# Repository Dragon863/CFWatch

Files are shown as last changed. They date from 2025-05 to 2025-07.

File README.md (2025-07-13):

# ⌚ CFWatch
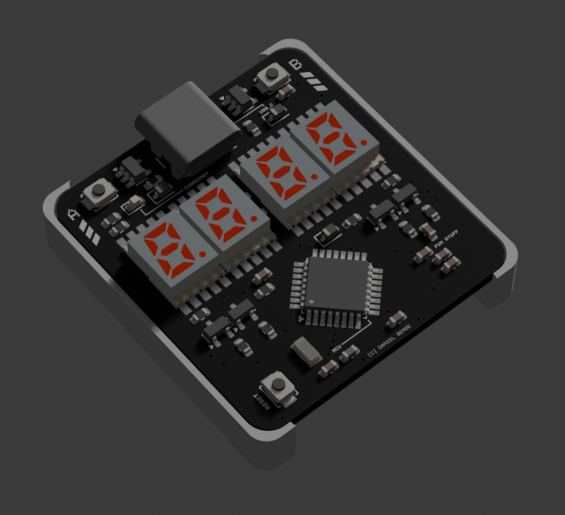
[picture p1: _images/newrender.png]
render


## What is this?

CFWatch is a project that I've been wanting to build for years now. I've always dreamed of building a watch, but was never quite sure where to start - sure, the pinetime and other hackable watches were really cool, but they never quite felt "personal" or quite reflective of the stuff I enjoy. Eventually I decided I'd just build my own, but I didn't really have the knowledge or skills to do so until very recently, so when [highway](https://highway.hackclub.com/) came along I decided it was finally time! The "CF" in "CFWatch" came from [r/cassettefuturism](https://old.reddit.com/r/cassettefuturism/top/?sort=top&t=all), a huge source of design inspiration for this

## Hardware Overview

The current revision has:
- USB-C charging & programming (requires bootloader)
- 4x red 7-segment displays
- 2x individually programmable buttons
- LIR2032 battery with theoretical battery life of several months (untested)
- SAMD21 microcontroller for low power usage

The board layout is optimised for being assembled with JLCPCB's PCBA service, with every component apart from the battery on the front of the PCB. I would recommend hand soldering the cell mount to save costs.

## Repository Layout

The repo is structured as follows:
- PCB-related KiCad files in the `PCB/`
- FreeCAD case design in `CAD/`
- Files for creating the cover render in `Blender/`
- For a rough BOM, see `BOM.csv`
- For my development log, see `JOURNAL.md

> [!CAUTION]
> Version 1 has SEVERAL known issues! If you plan to use this to have your own manufactured, please use the V2 design made in EasyEDA and double check everything in the schematic and PCB; I am not responsible for any non-functional boards!

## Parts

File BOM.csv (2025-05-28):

Item | Estimated price
PCB Assembly (JLCPCB) | $110
J-Link clone (Aliexpress) | $10
2x Keystone 1060 coin cell holders (LCSC) | $9
2x LIR2032 coin cells (Aliexpress) | $5

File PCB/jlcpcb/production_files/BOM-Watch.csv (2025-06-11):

Comment | Designator | Footprint | LCSC | Quantity
2.2uH | L1 | L_0805_2012Metric | C1043 | 1
MCP73831-2-OT | U1 | SOT-23-5 | C14879 | 1
36.5k | R21 | R_0402_1005Metric | C15011 | 1
TPS63900 | U2 | WSON-10-1EP_2.5x2.5mm_P0.5mm_EP1.2x2mm_ThermalVias | C1518762 | 1
D | D1,D2 | D_SOD-323 | C191023 | 2
4.7u | C8 | C_0603_1608Metric | C19666 | 1
KCSA02-105 | Dig1,Dig2,Dig3,Dig4 | KCSC02-105 | C22462656 | 4
SW_Push | SW1,SW3,SW4 | SW_SPST_B3U-1000P | C231329 | 3
150 | R13,R14,R15,R16,R6,R7,R8,R9 | R_0402_1005Metric | C25082 | 8
220 | R4 | R_0402_1005Metric | C25091 | 1
390 | R17,R18,R19,R20 | R_0402_1005Metric | C25109 | 4
10k | R5 | R_0402_1005Metric | C25744 | 1
27k | R1 | R_0402_1005Metric | C25771 | 1
5.1k | R2,R3 | R_0402_1005Metric | C25905 | 2
USB_C_Receptacle_USB2.0_14P | J1 | USB_C_Receptacle_HCTL_HC-TYPE-C-16P-01A | C2988369 | 1
32768Hz | Y2 | Crystal_SMD_3215-2Pin_3.2x1.5mm | C32346 | 1
10pF | C10,C9 | C_0402_1005Metric | C32949 | 2
LED | D3 | LED_0402_1005Metric | C33115 | 1
1uF | C1,C5,C6,C7 | C_0402_1005Metric | C52923 | 4
2N3906 | Q1,Q2,Q3,Q4 | SOT-23 | C5300004 | 4
22uF | C_OUT1 | C_0603_1608Metric | C59461 | 1
ATSAMD21E18A-A | U7 | TQFP-32_7x7mm_P0.8mm | C618770 | 1
10uF | C_IN1 | C_0603_1608Metric | C96446 | 1

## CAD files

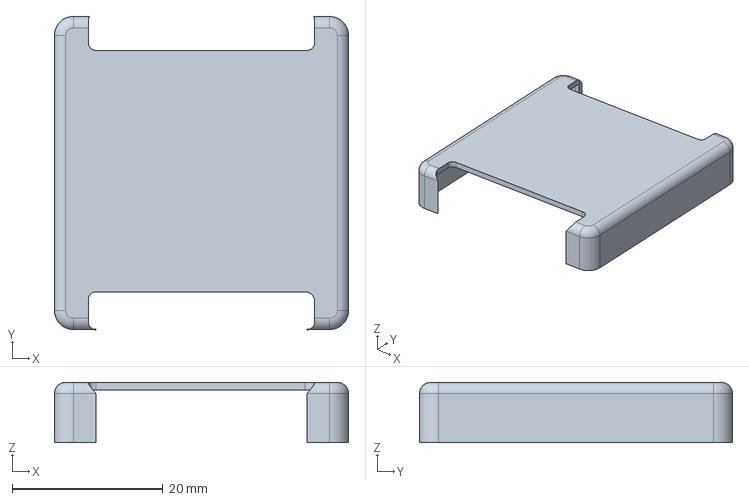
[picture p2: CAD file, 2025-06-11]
CAD/watch.FCStd
39.0 x 41.5 x 8.00 mm

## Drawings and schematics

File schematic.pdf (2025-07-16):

GND B1A12 VBUS B4A9 CC2 B5 SBU1 A8 DP2 B6 DN1 A7 DP1 A6 DN2 B7 CC1 A5 SBU2 B8 VBUS A4B9 GND A1B12

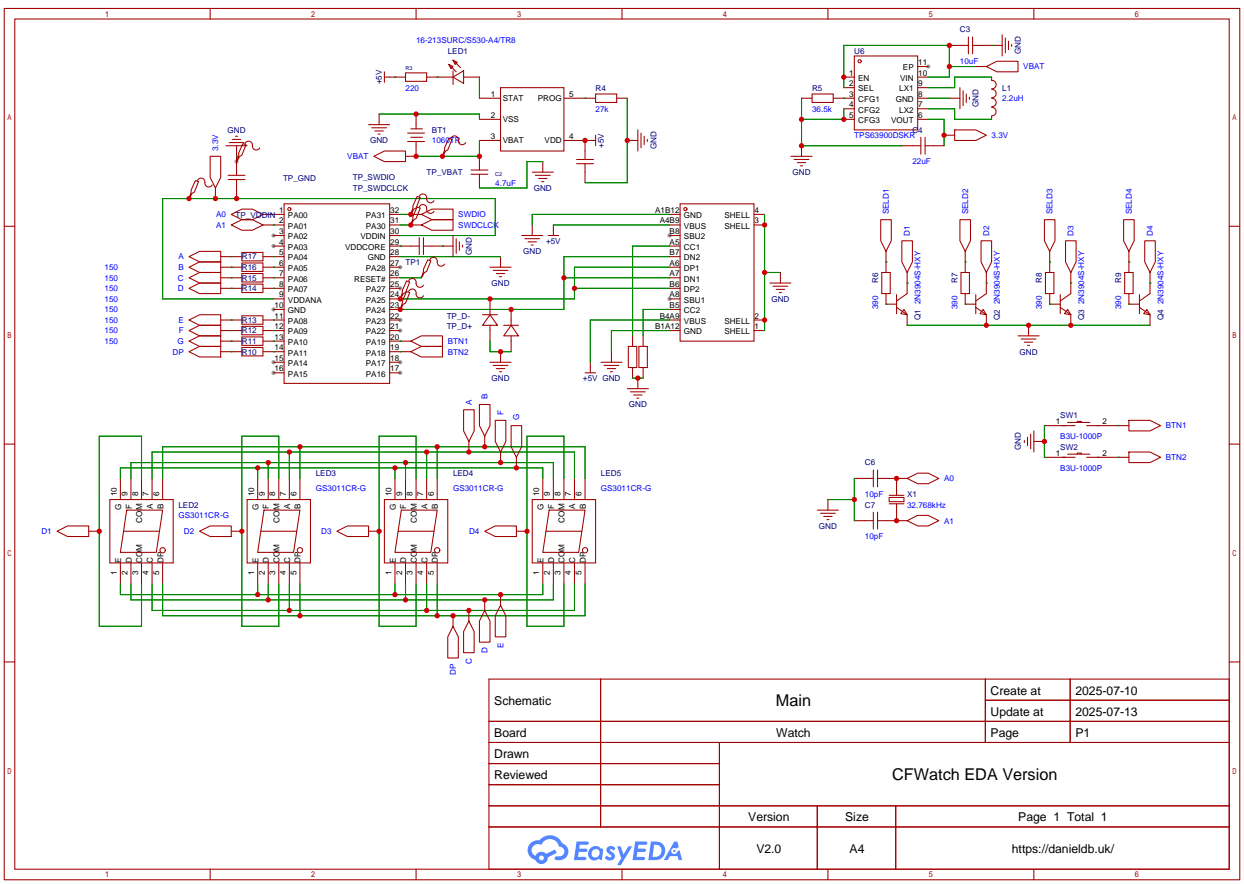
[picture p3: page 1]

Schematic | Main | Create at | 2025-07-10

Update at | 2025-07-13

Board | Watch | Page | P1
Drawn | | CFWatch EDA Version
Reviewed

Version | Size | Page 1 Total 1

V2.0 | A4 | https://danieldb.uk/

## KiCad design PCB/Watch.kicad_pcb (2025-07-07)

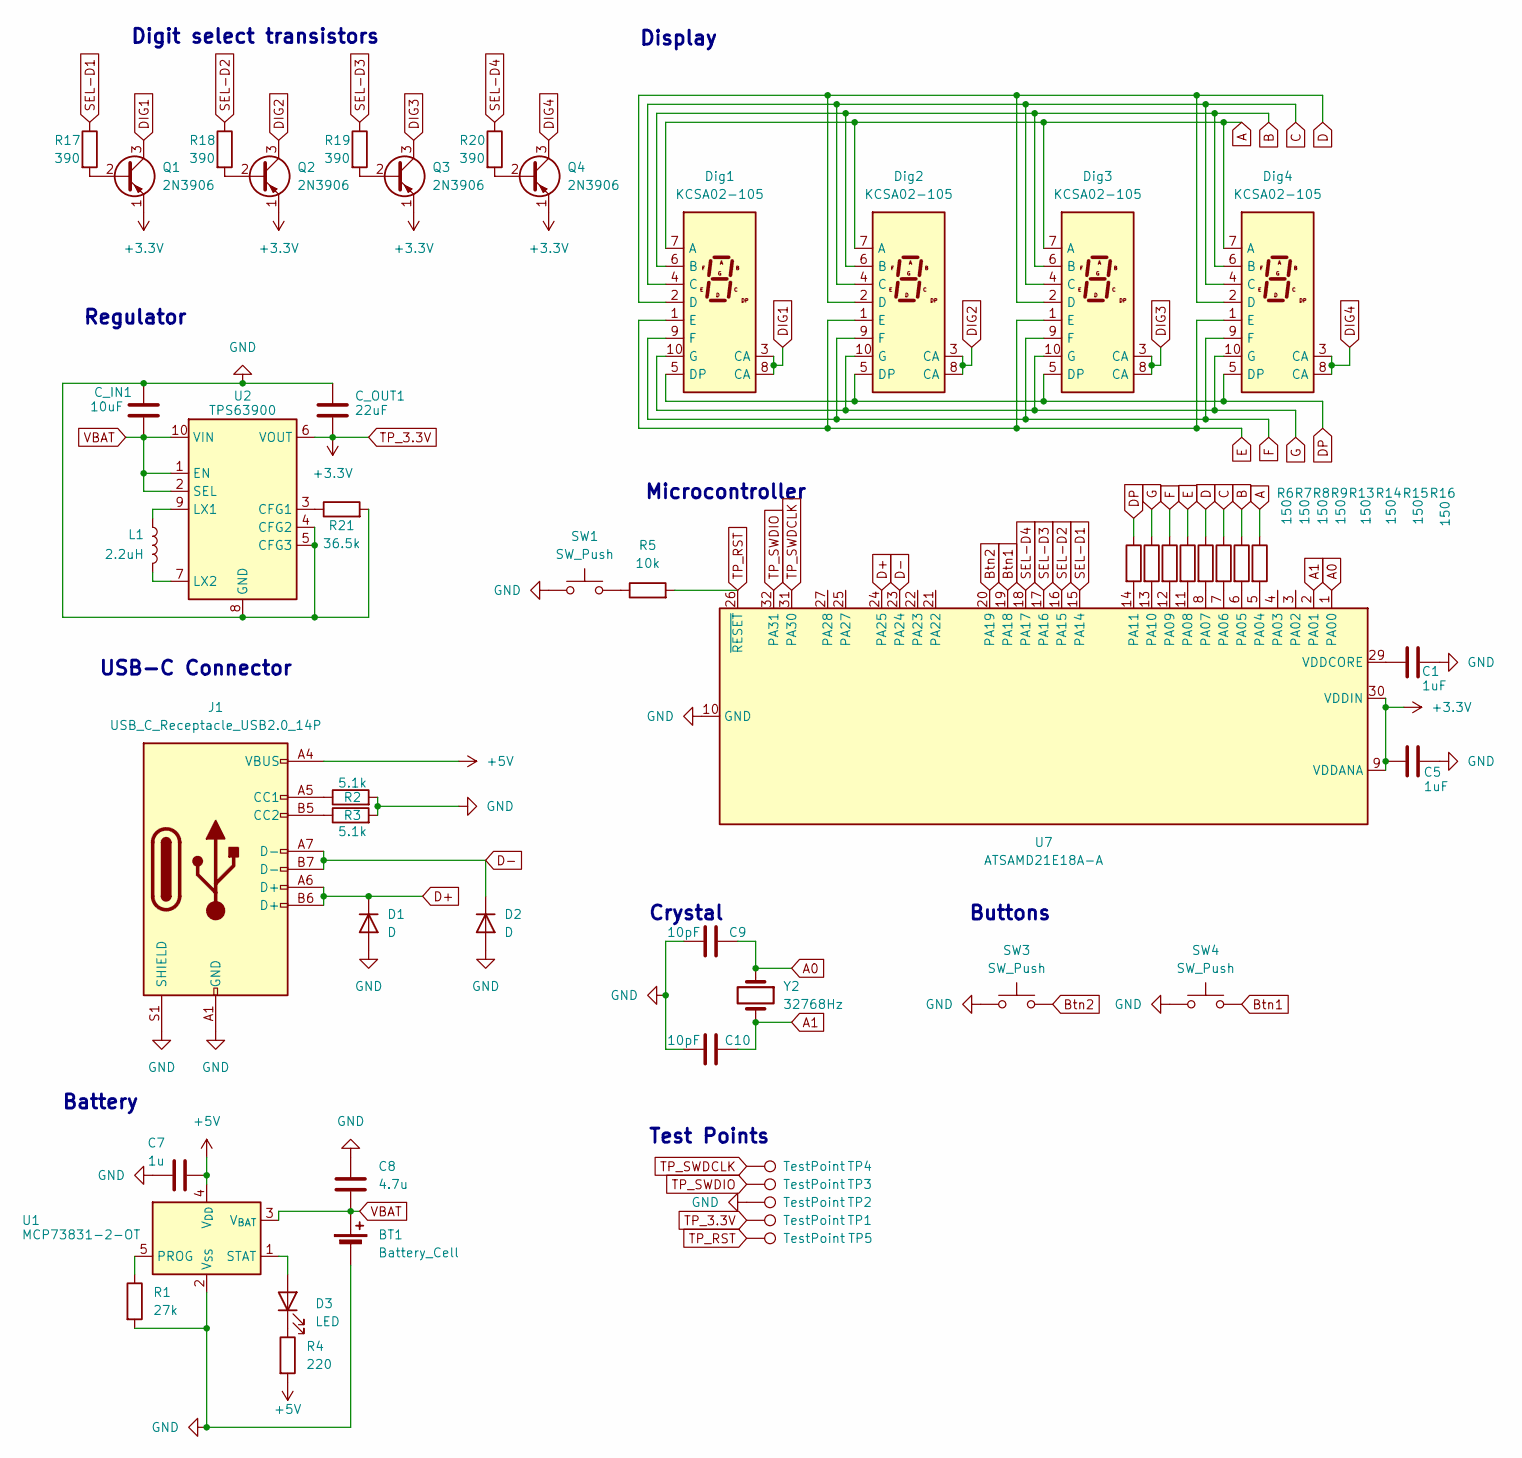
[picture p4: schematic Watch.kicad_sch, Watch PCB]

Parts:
BT1: Battery_Cell; BatteryHolder_Keystone_1060_1x2032
C1, C5: 1uF; C_0402_1005Metric
C7: 1u; C_0402_1005Metric
C8: 4.7u; C_0603_1608Metric
C9, C10: 10pF; C_0402_1005Metric; MPN CL21C100JBANNNC
C_IN1: 10uF; C_0603_1608Metric
C_OUT1: 22uF; C_0603_1608Metric
D1, D2: D; D_SOD-323
D3: LED; LED_0402_1005Metric
Dig1, Dig2, Dig3, Dig4: KCSA02-105; KCSC02-105
J1: USB_C_Receptacle_USB2.0_14P; USB_C_Receptacle_HCTL_HC-TYPE-C-16P-01A
L1: 2.2uH; L_0805_2012Metric
Q1, Q2, Q3, Q4: 2N3906; SOT-23
R1: 27k; R_0402_1005Metric
R2, R3: 5.1k; R_0402_1005Metric
R4: 220; R_0402_1005Metric
R5: 10k; R_0402_1005Metric
R6, R7, R8, R9, R13, R14, R15, R16: 150; R_0402_1005Metric
R17, R18, R19, R20: 390; R_0402_1005Metric
R21: 36.5k; R_0402_1005Metric
SW1, SW3, SW4: SW_Push; SW_SPST_B3U-1000P
TP1, TP2, TP3, TP4, TP5: TestPoint; TestPoint_Pad_D1.0mm
U1: MCP73831-2-OT; SOT-23-5
U2: TPS63900; WSON-10-1EP_2.5x2.5mm_P0.5mm_EP1.2x2mm_ThermalVias
U7: ATSAMD21E18A-A; TQFP-32_7x7mm_P0.8mm
Y2: 32768Hz; Crystal_SMD_3215-2Pin_3.2x1.5mm

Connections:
+5V: C7.2, J1.A4 (VBUS), J1.A9 (VBUS), J1.B4 (VBUS), J1.B9 (VBUS), R4.2, U1.4 (V_{DD})
A: Dig1.7 (A), Dig2.7 (A), Dig3.7 (A), Dig4.7 (A), R16.1
A0: C9.1, U7.1 (PA00), Y2.1
A1: C10.1, U7.2 (PA01), Y2.2
B: Dig1.6 (B), Dig2.6 (B), Dig3.6 (B), Dig4.6 (B), R15.1
Btn1: SW4.2, U7.19 (PA18)
Btn2: SW3.2, U7.20 (PA19)
C: Dig1.4 (C), Dig2.4 (C), Dig3.4 (C), Dig4.4 (C), R14.1
D: Dig1.2 (D), Dig2.2 (D), Dig3.2 (D), Dig4.2 (D), R13.1
D+: D1.1 (K), J1.A6 (D+), J1.B6 (D+), U7.24 (PA25)
D-: D2.1 (K), J1.A7 (D-), J1.B7 (D-), U7.23 (PA24)
DIG1: Dig1.3 (CA), Dig1.8 (CA), Q1.3 (C)
DIG2: Dig2.3 (CA), Dig2.8 (CA), Q2.3 (C)
DIG3: Dig3.3 (CA), Dig3.8 (CA), Q3.3 (C)
DIG4: Dig4.3 (CA), Dig4.8 (CA), Q4.3 (C)
DP: Dig1.5 (DP), Dig2.5 (DP), Dig3.5 (DP), Dig4.5 (DP), R6.1
E: Dig1.1 (E), Dig2.1 (E), Dig3.1 (E), Dig4.1 (E), R9.1
F: Dig1.9 (F), Dig2.9 (F), Dig3.9 (F), Dig4.9 (F), R8.1
G: Dig1.10 (G), Dig2.10 (G), Dig3.10 (G), Dig4.10 (G), R7.1
unnamed: D3.2 (A), U1.1 (STAT)
unnamed: D3.1 (K), R4.1
unnamed: J1.A5 (CC1), R2.1
unnamed: J1.B5 (CC2), R3.1
unnamed: Q1.2 (B), R17.2
unnamed: Q2.2 (B), R18.2
unnamed: Q3.2 (B), R19.2
unnamed: Q4.2 (B), R20.2
unnamed: R5.1, SW1.2
unnamed: R1.1, U1.5 (PROG)
unnamed: R21.1, U2.3 (CFG1)
unnamed: L1.1, U2.9 (LX1)
unnamed: L1.2, U2.7 (LX2)
unnamed: R16.2, U7.5 (PA04)
unnamed: R15.2, U7.6 (PA05)
unnamed: R14.2, U7.7 (PA06)
unnamed: R13.2, U7.8 (PA07)
unnamed: R9.2, U7.11 (PA08)
unnamed: R8.2, U7.12 (PA09)
unnamed: R7.2, U7.13 (PA10)
unnamed: R6.2, U7.14 (PA11)
unnamed: C1.1, U7.29 (VDDCORE)
SEL-D1: R17.1, U7.15 (PA14)
SEL-D2: R18.1, U7.16 (PA15)
SEL-D3: R19.1, U7.17 (PA16)
SEL-D4: R20.1, U7.18 (PA17)
TP_3.3V: C5.1, C_OUT1.2, Q1.1 (E), Q2.1 (E), Q3.1 (E), Q4.1 (E), TP1.1, U2.6 (VOUT), U7.9 (VDDANA), U7.30 (VDDIN)
TP_RST: R5.2, TP5.1, U7.26 (~RESET)
TP_SWDCLK: TP4.1, U7.31 (PA30)
TP_SWDIO: TP3.1, U7.32 (PA31)

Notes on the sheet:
Battery
Crystal
Display
Test Points
Microcontroller
Digit select transistors
Regulator
Buttons
USB-C Connector

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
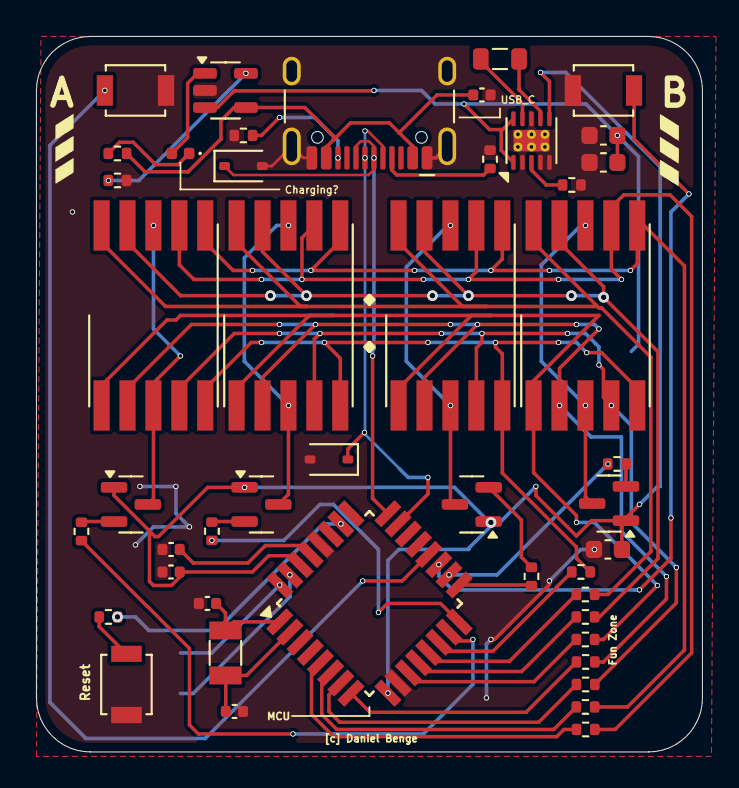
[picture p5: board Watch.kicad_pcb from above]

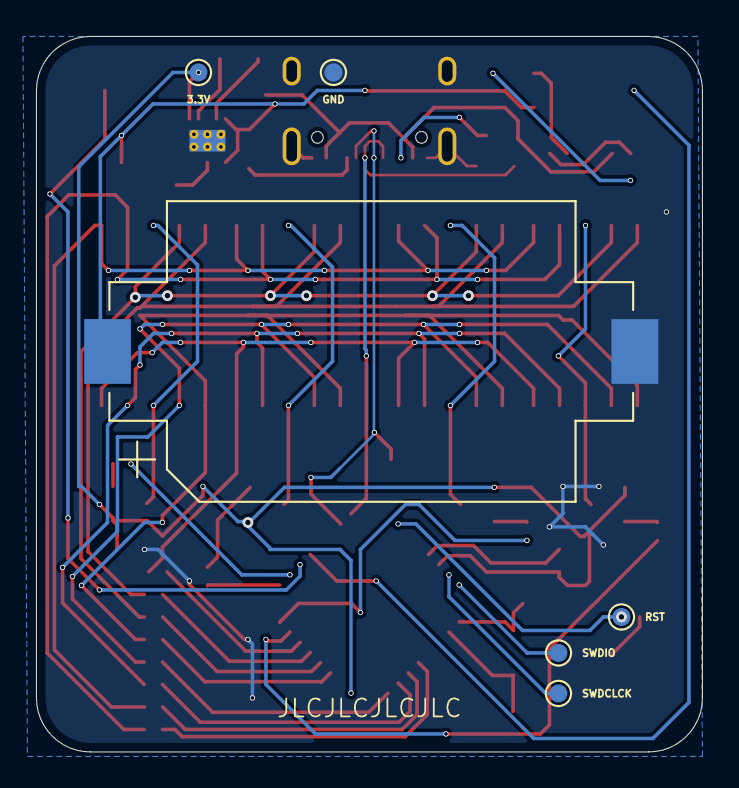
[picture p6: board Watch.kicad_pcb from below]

Board: 2 copper layers, 37.0 x 39.8 mm, 54 parts (6 on the bottom side), 51 nets.

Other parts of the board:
G1: LOGO
graphic2: LOGO

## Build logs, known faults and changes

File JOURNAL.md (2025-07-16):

---
title: "CFWatch"
author: "Daniel Benge (@Dragon863 on Slack)"
description: "It's a watch! But custom! Wow!"
created_at: "2025-05-18"
---

# CFWatch Development Journal

**Total time spent:** around 25hrs

## Session 1

**And so it begins!** The goal here is to build a watch I'd genuinely be happy to wear daily, with non-intrusive charging circuitry and decent battery life. I've been loving the posts in [r/cassettefuturism](https://reddit.com/r/cassettefuturism/top/?sort=top&t=all) lately, so something fitting that vibe would just be awesome to build! I'm leaning towards 7 segment displays rather than one of those cheap 0.96" oleds or a round LCD/TFT display, simply because in my opinion they look a lot less cheap and can convey what I need them to easily. I think the main challenges here are going to be durability, making something that doesn't cost a fortune to assemble, and driving displays from a microcontroller. Here are my current ideas:
- Something like the KCSC02-105 for a surface-mounted 7 segment display
- Possibly a nRF or SAMD21 microcontroller for low power usage
- A LIR2032 rechargeable button cell for the battery seeing as the CR2032 in the same form factor is super popular and has a lot of mountings available

Here are some designs that inspired me:
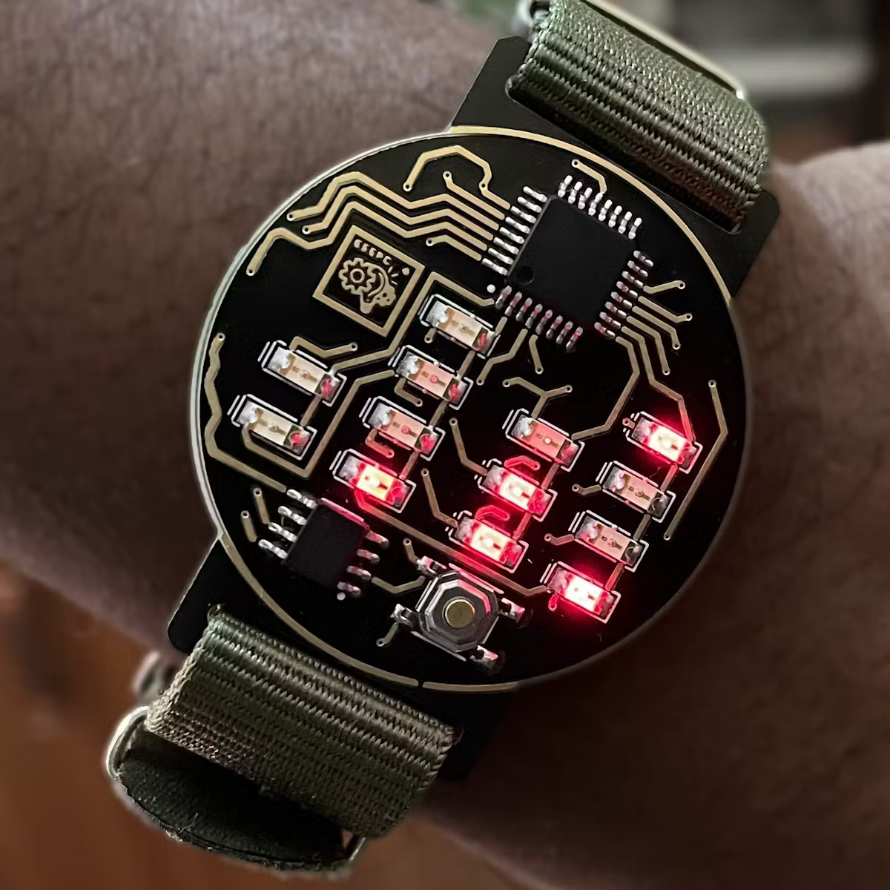
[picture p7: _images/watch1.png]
Watch 1
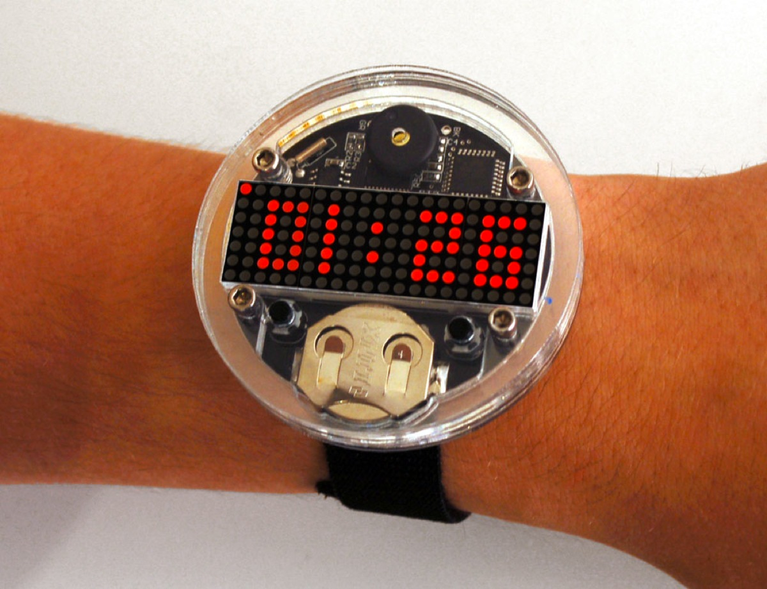
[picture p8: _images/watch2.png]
Watch 2
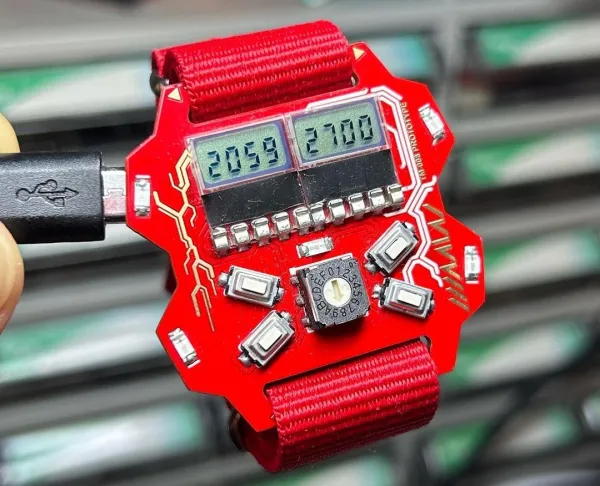
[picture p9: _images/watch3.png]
Watch 3
|  |  |  |
| :---: | :---: | :---: |
| Cool binary display | LOVE this LED matrix!! |  USB and *very* nice displays  |

I've created a schematic in this session that I'm fairly certain is a good starting point, but it is definitely subject to change a lot! I included:
1. A battery and charging circuit using the *MCP73831-2-OT*
2. A USB C port with the appropriate resistors for 5V input
3. A 5V-3.3V step down with the *AP2112K-3.3* (the SAMD21 uses 3.3V)
4. 4x 7 segment digits with transistors to select which digit is active - these are [charlieplexed](https://en.wikipedia.org/wiki/Charlieplexing) to reduce pins necessary to drive them!

I made it by breaking down the design into smaller chunks, with the first challenge being power regulation. 
- The SAMD21 uses 3.3V power, whereas a LIR2032 cell gives a wide range and USB-C typically deliver 5V as a standard. I solved this by having the USB and cell feed into a step down converter as mentioned above, supplying a steady feed to the MCU
- The displays themselves are charlieplexed using 4 transistors, each selecting a digit and allowing it to be driven. I'm sure this will be difficult to manage in software, but that's a problem for future me :)
- I've never really done much with a bare metal microcontroller before, so I did quite a bit of research on how to power them; the datasheet for the one I'm using said to add capacitors on all the power lines, and I used diodes too just as a precaution to prevent anything being fried by reverse polarity
- Another fun issue is actually keeping the time; to save space I really didn't want to add a whole RTC, which meant I needed the internal clock of the MCU to be as accurate as possible. How did I do that? Adding a crystal! I won't pretend I didn't use a ton of references from other people's projects here, since I have never paid attention to crystals in schematics before so haven't a clue how they should be wired
KiCad's labels are severely underrated too, this whole schematic looks really clean, but I would never have managed it without them!

I made a significant chunk of progress in this first session, but a lot will be changing as I learn more about how to design a project like this!

*(session duration: ~6hrs!)*

## Session 2

It's time for laying out the PCB! I once attempted to make a PCB watch before, but it ended up being very expensive to order from JLCPCB because it required double sided assembly, so this time I wanted to keep everything but the battery on the front. Here's what I ended up with:

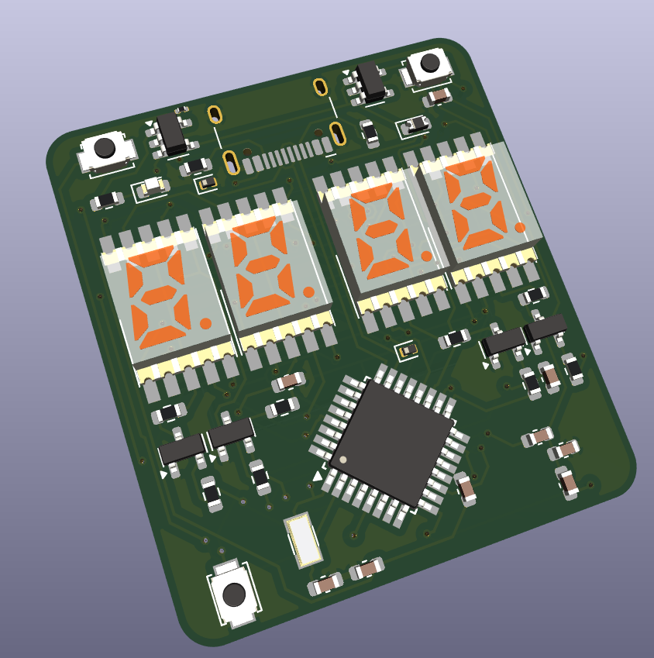
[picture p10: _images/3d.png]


And prepare yourself for autorouter torture!

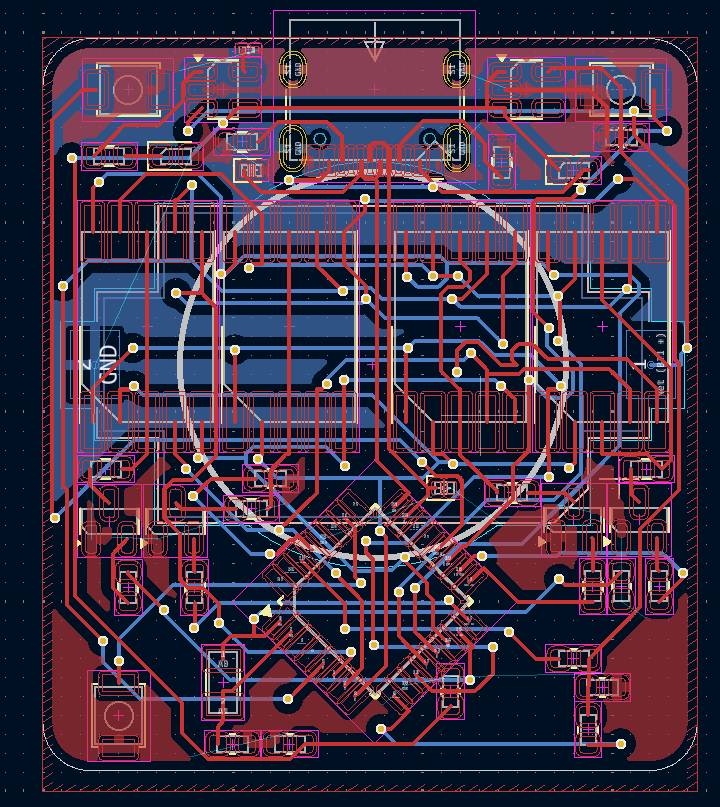
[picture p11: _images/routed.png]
routing


I also changed quite a bit in the schematic; first of all I switched the resistors for the displays to be in series with the common anode rather than for each segment, gaining me valuable board space. I have the SAMD21 at 45 degrees to make it easier to route and also fit on the watch (which ended up being about 35x40mm in this revision)

*(session duration: ~4 hrs)*

## Session 3

What's one important thing this watch is missing? Probably a case! I've been putting this off since I'm completely new to CAD, but this is a great time for me to learn. Initially I tried OnShape before quickly learning I did not enjoy using it at all, and switched over to FreeCAD, which when it isn't randomly crashing is an excellent piece of open source software! Getting the hang of constraints wasn't very easy, but once I got my head around it they did make quite a lot of sense. I also exported a `.wrl` of my PCB from KiCad and a STL from FreeCAD to check they fitted together, I've added a render below:

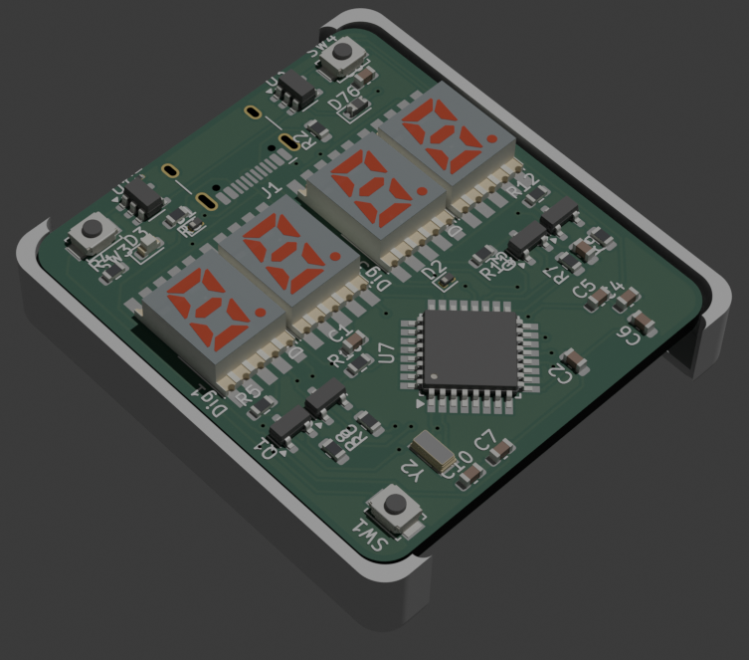
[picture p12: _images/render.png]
3d render


This was really interesting to play around with, and I learned a ton about CAD in the process! The main issue I faced was with the battery cell - almost every mount for a CR2032 cell (I'll be using a compatible but rechargeable LIR2032) was at least 4.5mm tall, which makes it difficult to design a case without it being super tall.

*(session duration: honestly I split this into a few sections and completely lost track. Maybe 6 hours total?)*

## Session 4

This session was mostly focussed on cleaning up the watch and readying it for production. I did this in about 3 sessions in reality, but since they were all pretty similar I'll write it up in one. Enough preamble, let's get into it!
The first thing I did was to get some sensible footprints assigned. Turns out, using 0603 for everything was a stupid decision - especially for diodes. I did have to use small footprints for nearly everything, since 4x4cm is pretty tiny in the grand scheme of things
Next was routing vias... turns out, autorouter sucks, especially with such a tiny board. I routed it all by hand which led to something a bit like this:

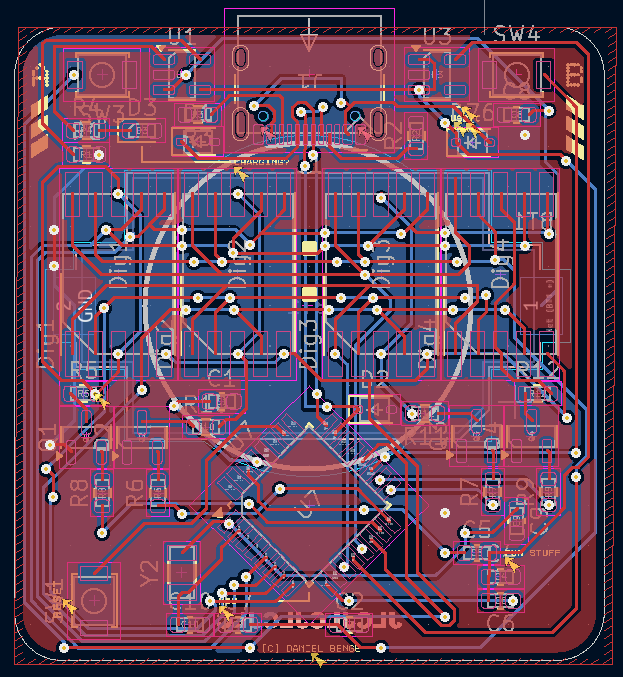
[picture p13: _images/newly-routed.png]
new routed design


The main issues was that the 7 segment displays made it really hard to route anything near them since they hard 10 pins each. I had to increase the board size by a few mm too, just to make enough room for traces near the edges, and I added the JLCPCB order placeholder on the back too. The main reason everything was so difficult to lay out was that to stay under my $150 budget, I had to keep everything on one side of the board to save the $50 fee JLCPCB adds for double sided assembly (which is fair enough really, I can't imagine it's easy to do with a pick and place machine)

With that done, I moved on to the case - since I changed the board shape I needed to update the 3d model. I increased the size a little, and rounded the corners more to make it much more aesthetically pleasing/

Okay, almost done now! I uploaded this draft of the design to JLC to get a rough estimate of the cost, and it came out to about £70 as shown below. Personally I think that's a pretty amazing price when you consider how difficult assembling something like this can be!

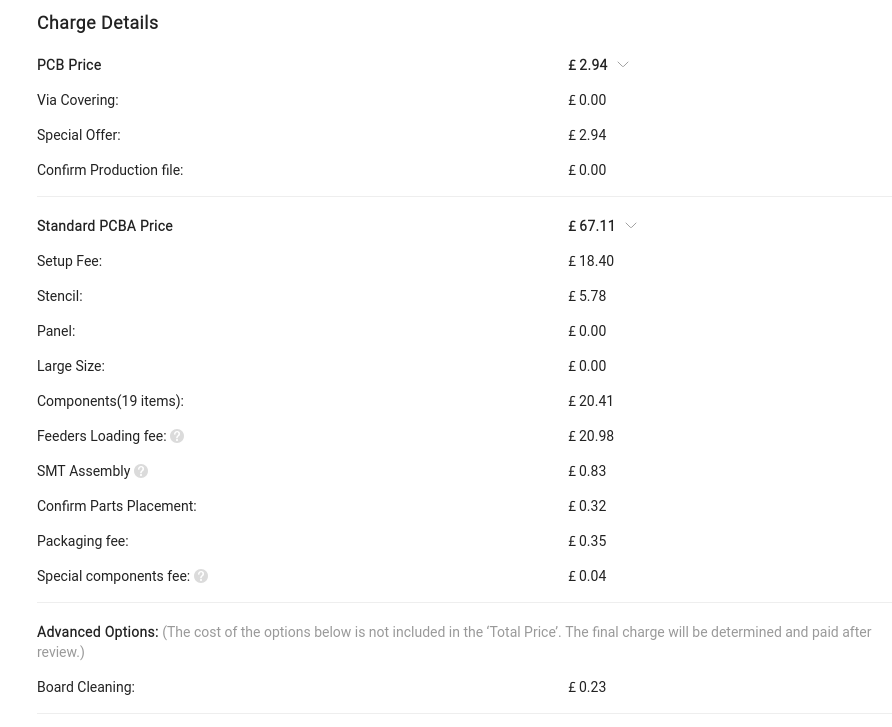
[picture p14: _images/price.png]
price


I also made a blender render of the current state:

render

*(session duration: roughly 8 hours in total, maybe more)*

## Session 5

This is it now! I resolved a few routing issues and added test pads for burning the bootloader since the SAMD21 doesn't come with a USB compatible bootloader by default, and I've also added the 3d model for the case to the repo. The main thing I did in this session was creating a rough BOM which I've listed below:

| Item | Estimated price |
| --- | --- |
| PCB Assembly (JLCPCB) | $110 |
| J-Link clone (Aliexpress) | $10 |
| 2x Keystone 1060 coin cell holders (LCSC)  | $9 |
| 2x LIR2032 coin cells (Aliexpress) | $5 |

The battery and holder are separate because I'll solder them manually to save on JLCPCB costs (double sided costs significantly more), and with that done the project is pretty much finished!

*(session duration: ~1 hr)*

## Session 6

After a fairly long wait, I received the boards from JLCPCB and tested them. The battery charger worked great, but I found two pretty major errors that prevent the board from functioning as it should. The first is the voltage regulator; instead of being connected to Vin, the SEL pin was shorted to ground, meaning that the regulator defaulted to an output voltage of 1.8V on the main 3.3V power rail. This wouldn't be too much of an issue other than causing a low brightness on the displays; 1.8V is still within the operating range of the SAMD21. Because of this, I moved on to testing flashing a USB bootloader. After several hours of debugging with OpenOCD using various adapters, I came to the conclusion that something was causing the microcontroller to reset every ~0.1 seconds, rendering it impossible to flash any program to the board. This was confusing, so initially I tried shorting the debug pad for the RESET pin to the power rail to prevent it from doing this, but it didn't help. 
After this I decided to review the schematic to find the issue, and it was fairly obvious...

|    |
| -- |
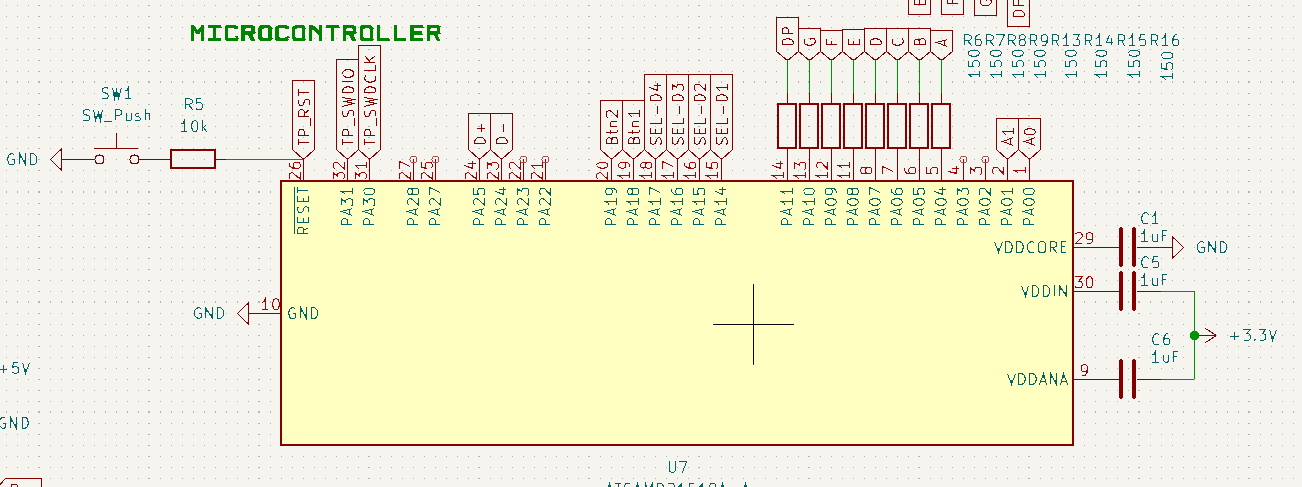
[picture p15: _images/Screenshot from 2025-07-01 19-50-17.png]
screenshot of schematic
|               |
| Capacitors C5 and C6 should connect to ground, with VDDIN and VDDANA connected to 3.3V |

This prevented the MCU getting power, so constant brownout errors were occurring. Originally I was going to bridge caps C5 and C6 to direct power in, but these capacitors were almost essential when running on battery because without them the board would randomly reset and lose the time. I concluded that another production run with corrected schematic was necessary.

*(session duration: ~5 hrs)*

## Session 7

I decided to remake the board in EasyEDA Pro pretty much from scratch. The schematic is the same as the previous version for all the working parts, but I also incorporated fixes for the regulator, power rail, reset button and input capacitors as well as adding a ton of test points just in case. The first stage was getting used to EasyEDA - it's much better than the last time I used it, but the keyboard shortcuts are completely different to KiCad's! After some adjusting I managed to get a complete schematic made, with fixed power input and a tweaked layout design.

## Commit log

2025-05-19 session 2
    [Watch.kicad_pcb, Watch.kicad_sch]
2025-05-27 Add blender, session 4, new render
    [Watch.kicad_pcb, Watch.kicad_sch]
2025-05-28 Fix PCB by adding test points
    [Watch.kicad_pcb, Watch.kicad_sch]
2025-05-28 Better test points
    [Watch.kicad_pcb, Watch.kicad_sch]
2025-05-28 Tiny improvements
    [Watch.kicad_pcb]
2025-05-28 Session 5 + BOM
    [watch.FCStd]
2025-05-28 Add csv BOM
    [BOM.csv]
2025-05-28 Restructure everything :)
    [BOM-Watch.csv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]
2025-06-11 Switch regulator
    [BOM-Watch.csv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]
2025-06-11 Fix charge LED, display resistors
    [Watch.kicad_pcb, Watch.kicad_sch]
2025-06-11 Add resistor to reset button, small schematic changes
    [BOM-Watch.csv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]
2025-07-01 Update render, PCB
2025-07-07 Fix regulator and voltage issue, replace inductor with LED
    [Watch.kicad_pcb, Watch.kicad_sch]
